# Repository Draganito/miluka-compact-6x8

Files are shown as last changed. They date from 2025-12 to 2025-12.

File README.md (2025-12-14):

# miluka Compact 6x8

The miluka Compact 6x8 is a camera system providing a compact professional body for portrait, street, landscape, and more photography usecases.

The camera body allows use of many newer or classic lenses with the Mamiya RB 6x8 or Mamiya RB 6x7 film back.

STL Files for 3D Printing

STEP Files for CNC Milling

### Compatible Modern Lenses

| Manufacturer | Name | Focal Length/Max. Aperture | Max. Lens Coverage | Flange Focal Distance (mm) | Rear Lens Diameter (mm) | Compatible Helicoid |
|---|---|---|---|---|---|---|
| Schneider | Super Angulon XL | 58mm/f5.6 | 4x5 | 67.90 | 60.00 | 17-31 |
| Schneider | Super Angulon | 65mm/f5.6 | 4x5 | 72.50 | 57.00 | 25-55 |
| Schneider | Super Angulon | 90mm/f8 | 5x7 | 98.80 | 57.00 | 17-31+25-55 / 25-55+25-55 |
| Rodenstock  | Apo-Grandagon | 55mm/f4.5 | 4x5 | 65.50 | 60.00 | 17-31 |
| Rodenstock  | Grandagon N | 65mm/f4.5 | 4x5 | 68.00 | 51.00 | 17-31 |
| Rodenstock  | Grandagon N | 75mm/f4.5 | 4x5 | 79.80 | 60.00 | 25-55 |
| Rodenstock  | Grandagon N | 90mm/f6.8 | 4x5 | 91.50 | 60.00 | 17-31+25-55 |
| Nikon | Nikkor-SW | 65mm/f4 | 4x5 | 70.80 | 54.00 | 17-31 |
| Nikon | Nikkor-SW | 75mm/f4.5 | 4x5 | 81.30 | 60.00 | 17-31+17-31 |
| Nikon | Nikkor-SW | 90mm/f8 | 5x7 | 97.00 | 60.00 | 17-31+25-55 |
| Nikon | Nikkor-W | 105mm/f5.6 | 4x5 | 103.20 | 42.00 | 25-55+25-55 |
| Fuji | Fujinon-SWD | 65mm/f5.6 | 4x5 | 72.20 | 54.00 | 25-55 |
| Fuji | Fujinon-SW | 65mm/f8 | 4x5 | 71.00 | 48.00 | 17-31 |
| Fuji | Fujinon-SW | 75mm/f8 | 4x5 | 82.50 | 54.00 | 17-31+17-31 |
| Fuji | Fujinon-SW | 90mm/f8 | 5x7 | 99.40 | 64.00 | 17-31+25-55 / 25-55+25-55 |

+ plus many more classic lenses in Copal/Compur/Compound shutters from old plate or folding cameras (75mm to 110mm focal length).

### Construction and Use

- 3D printable (PLA+ recommended) or CNC millable (POM or aluminum recommended).
- Focusing via ground glass or zone focusing – ideal for street and travel photography.
- Thread inserts (e.g., Ruthex) for 3D print; cut threads for CNC.
- Ground glass holder fits 88×61×2.0 mm glasses (eBay).
- Requires M65 flange and helicoid(s) (17-31 mm, 25-55 mm, or combinations) – available on eBay.
- Size: Width: 118.2, Depth 41, Height 109.1mm
- Weight: POM ~400 g, PLA+ ~350 g, Aluminium ~760 g
- Minimum FFD with 17-31 Helicoid 64mm (41mm Body, 4mm Flange, 17mm Helicoid, 2mm Lensboard)

### License

Published as STEP and STL files under [CC BY-NC-ND 4.0](https://creativecommons.org/licenses/by-nc-nd/4.0/legalcode).

Inventor: Dragan Bojovic  
Commercial use prohibited. Private printing/milling allowed. No design changes. Attribution required.
December 2025

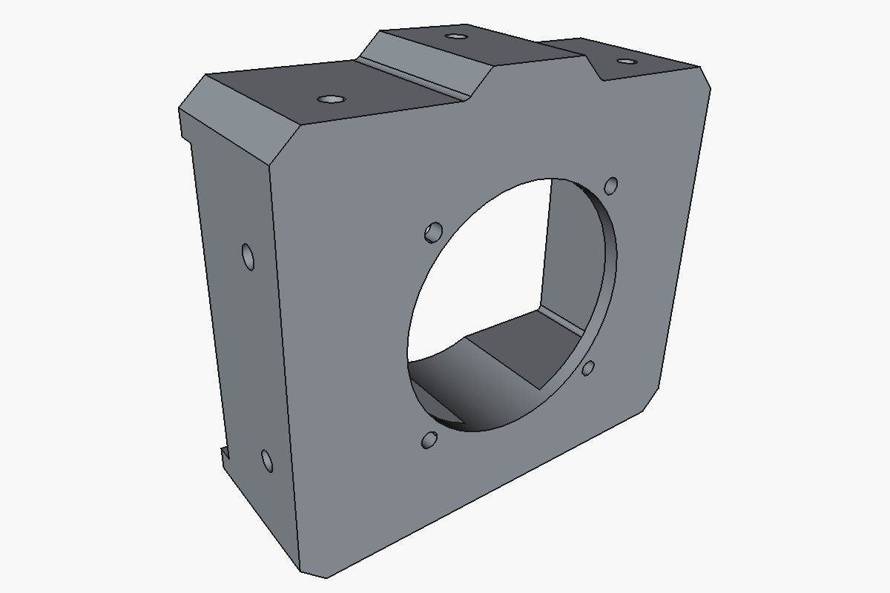
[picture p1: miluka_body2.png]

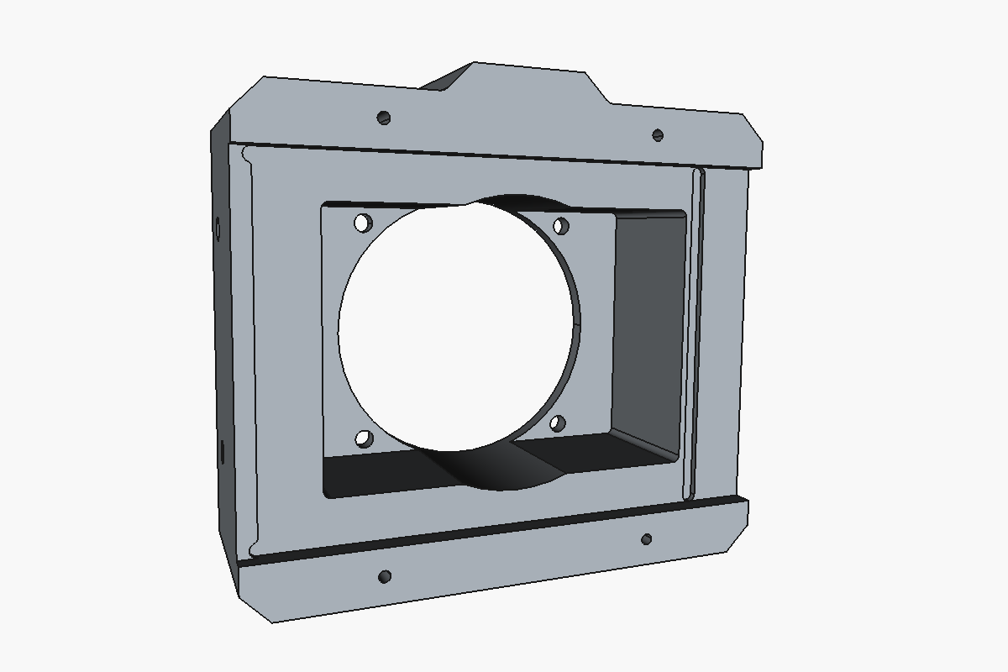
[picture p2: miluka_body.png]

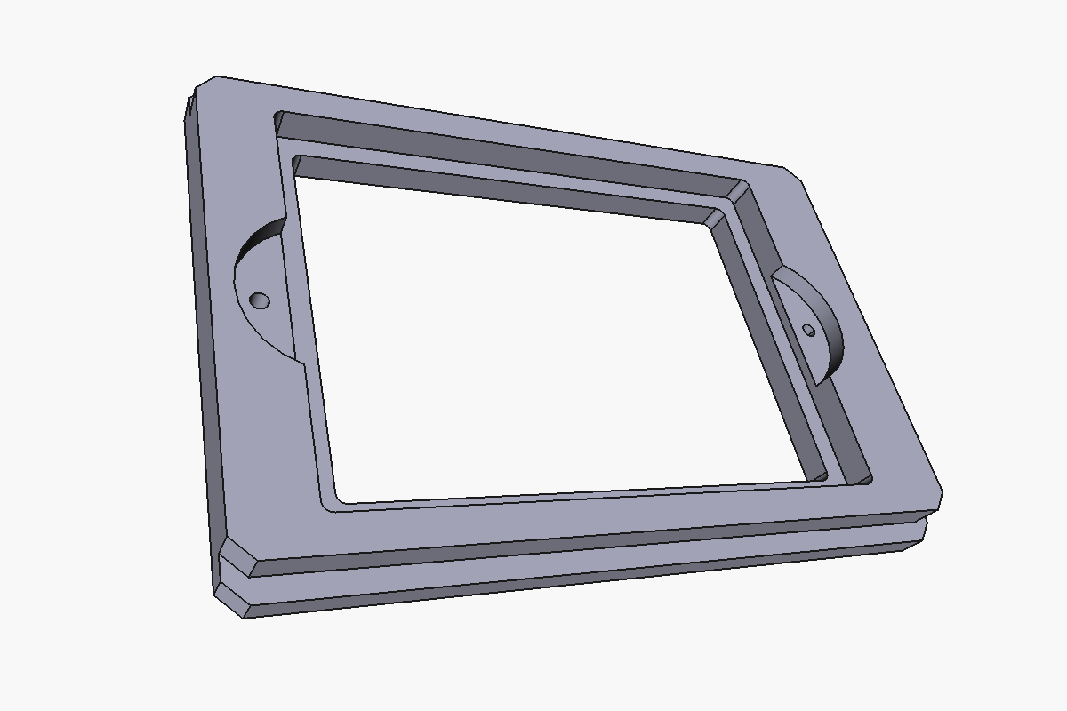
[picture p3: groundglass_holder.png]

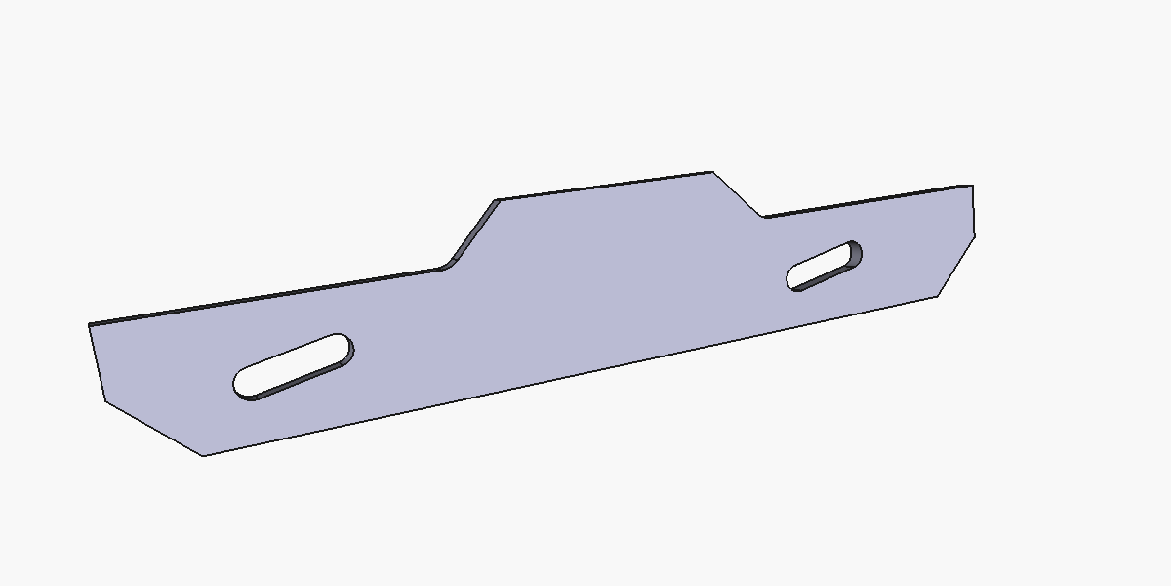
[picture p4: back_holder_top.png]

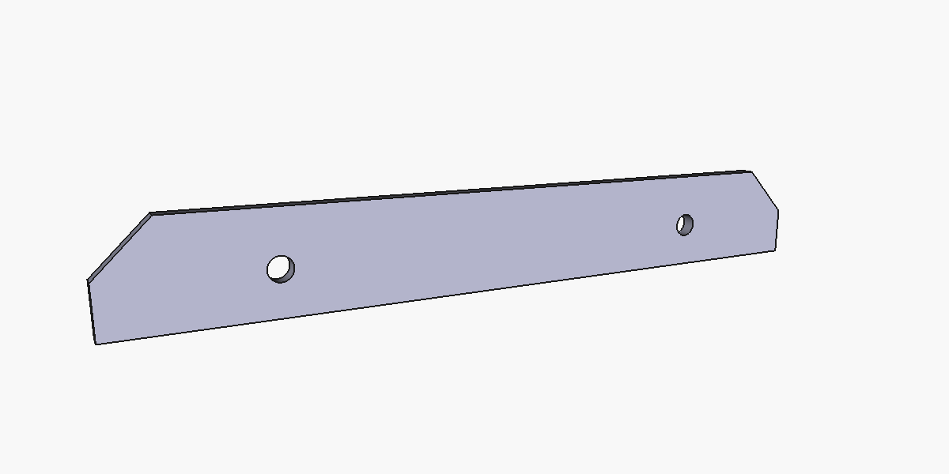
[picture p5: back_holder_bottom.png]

Prototype 1
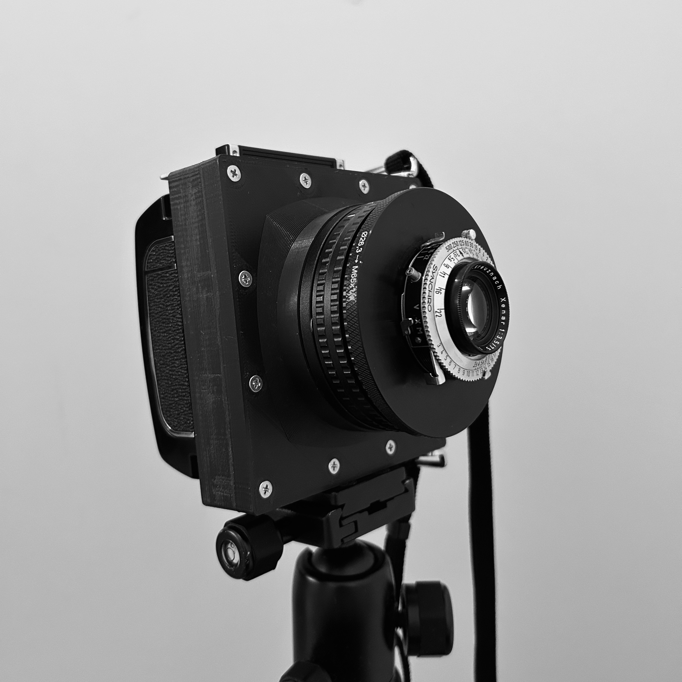
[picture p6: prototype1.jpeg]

Prototype 2
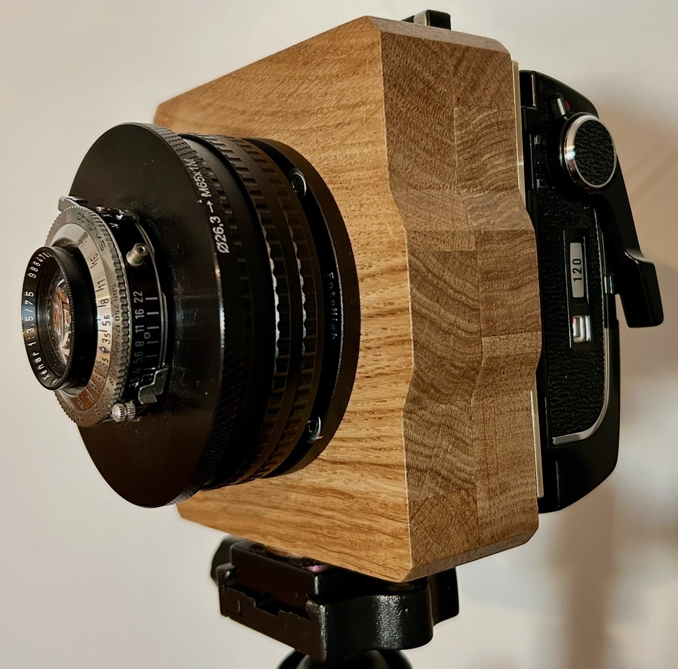
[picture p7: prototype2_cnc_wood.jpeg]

Prototype 3
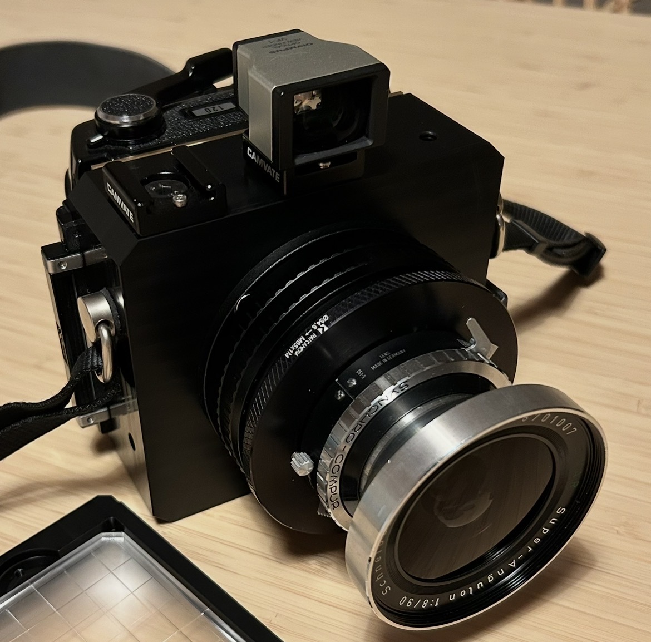
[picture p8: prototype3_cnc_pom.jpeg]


Ebay Parts Links:

Cold Shoe https://www.ebay.ch/itm/256756970307

Sling Screw for Strap https://www.ebay.ch/itm/406250562986

Sling Screw for Strap https://www.ebay.ch/itm/187712981477

Bright Ground Glass https://www.ebay.ch/itm/126527658529

Normal Ground Glass https://www.ebay.ch/itm/147021285483

17-31 Helicoid https://www.ebay.ch/itm/313543176067

25-55 Helicoid https://www.ebay.ch/itm/313542882203

Copal #00 Lensboard https://www.ebay.ch/itm/226102723622

Copal #0 Lensboard https://www.ebay.ch/itm/326906929939

Copal #1 Lensboard https://www.ebay.ch/itm/227124652209

Helicoid Flange M65 https://www.ebay.ch/itm/394637816375

first/old Github Project: https://github.com/Draganito/miluka-zone

Tool programmed for Body Design Simulation https://draganito.github.io/lens_sim/

First mention: https://forum.aphog.com/index.php?thread/64917-frankenstein-kamera-6x7/

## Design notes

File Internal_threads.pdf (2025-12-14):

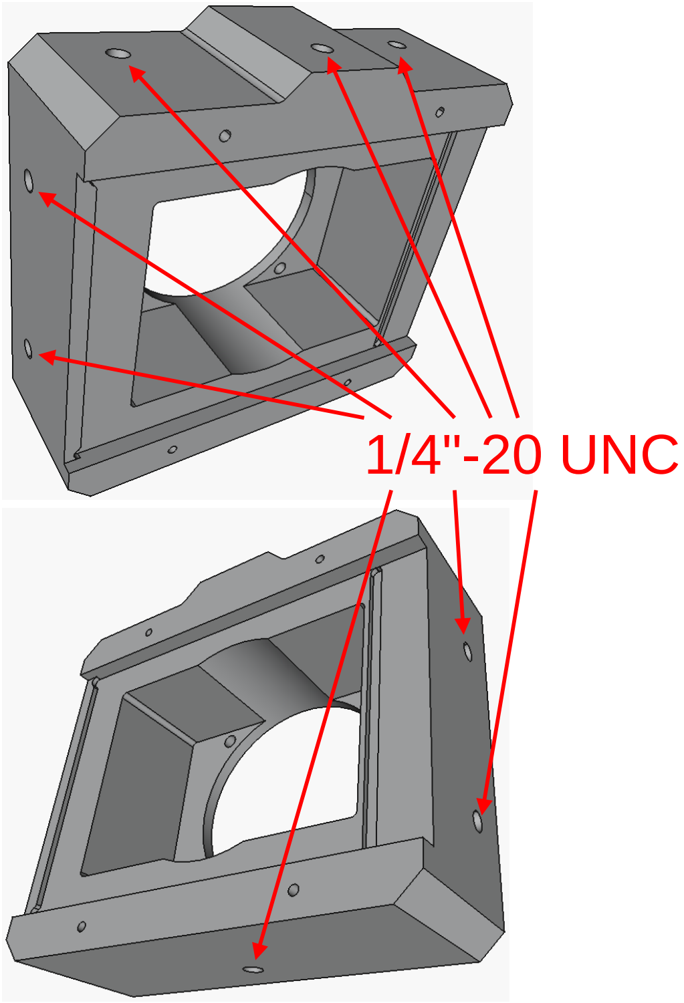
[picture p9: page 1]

1/4"-20 UNC

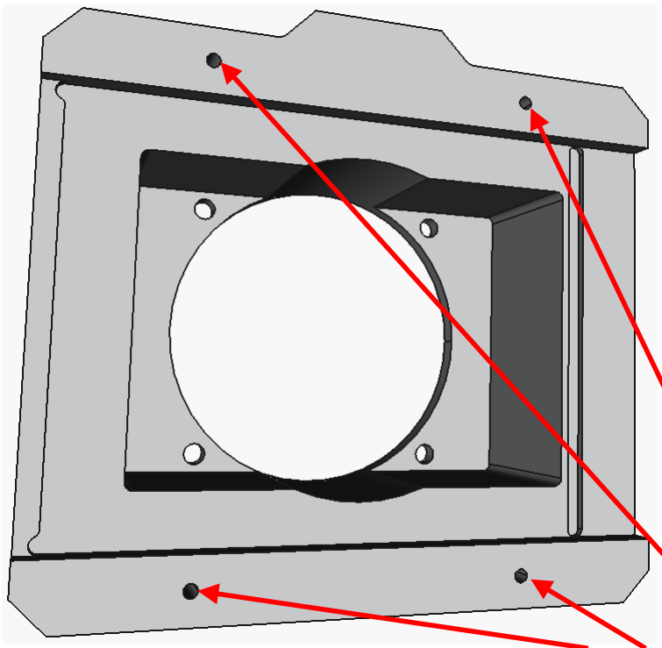
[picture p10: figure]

M3x0,5

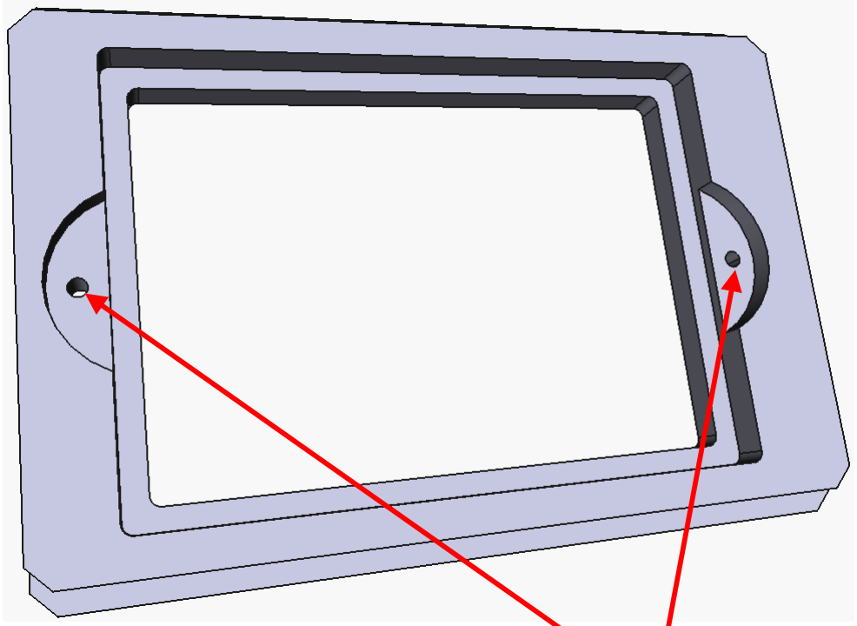
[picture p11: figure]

M3x0,5

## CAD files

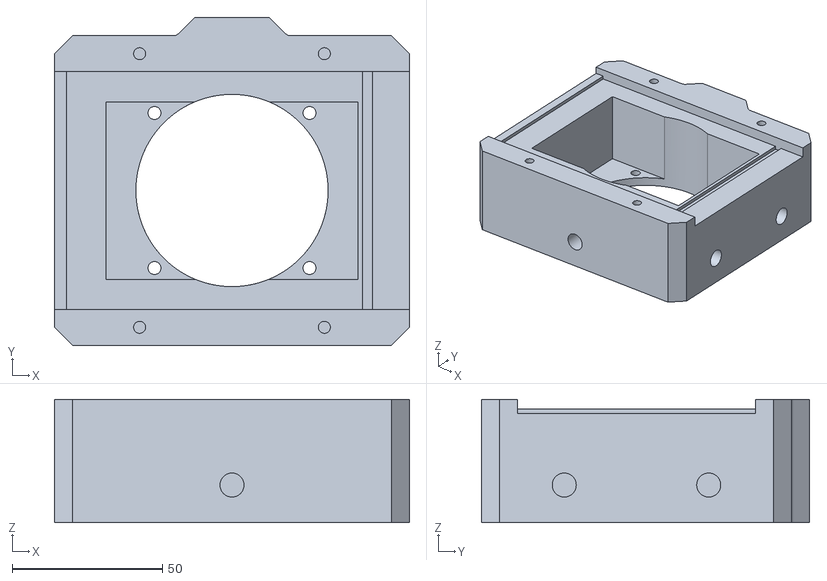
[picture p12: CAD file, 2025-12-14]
miluka_body_3d_print.stl
118.2 x 109.1 x 41.0

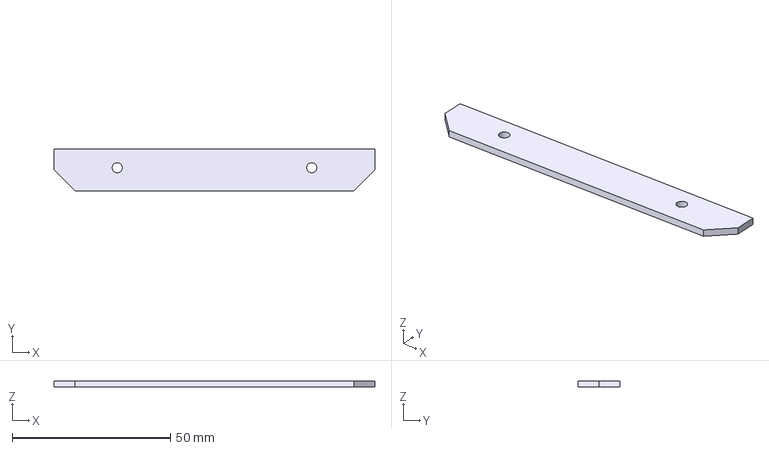
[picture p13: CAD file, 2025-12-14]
filmback_holder_bottom.step
101.5 x 13.4 x 2.00 mm

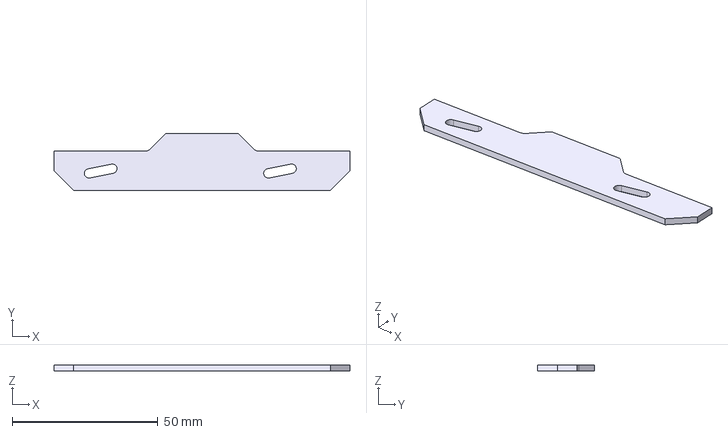
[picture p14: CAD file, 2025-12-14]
filmback_holder_top.step
101.5 x 19.4 x 2.00 mm

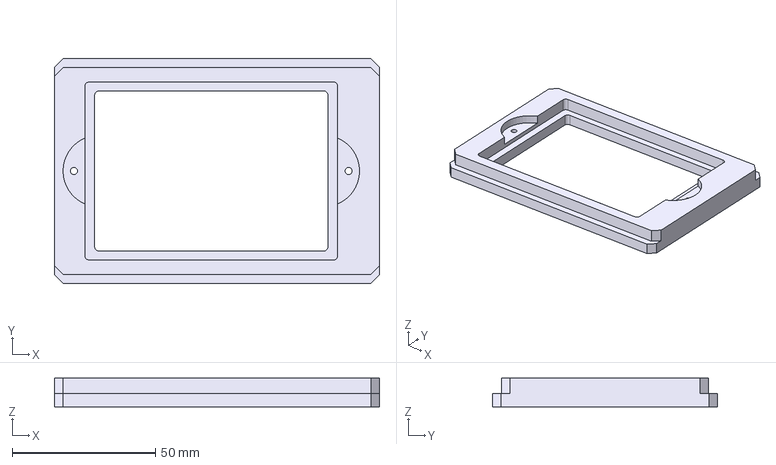
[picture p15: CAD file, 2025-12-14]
groundglass_holder.step
113.6 x 78.7 x 10.0 mm

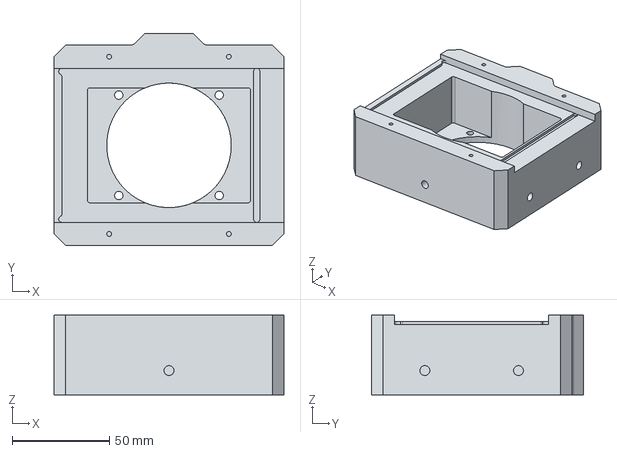
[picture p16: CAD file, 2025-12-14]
miluka_body_cnc.step
118.2 x 109.1 x 41.0 mm

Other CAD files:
filmback_holder_bottom.stl
filmback_holder_top.stl
groundglass_holder.stl

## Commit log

2025-12-14 Revise README with detailed camera system information
    Expanded the README to include detailed information about compatible lenses, construction, use, and licensing.
2025-12-14 Add prototype images to README
2025-12-14 Fix typo in README.md regarding lens description
2025-12-14 Add Normal Ground Glass link to README
